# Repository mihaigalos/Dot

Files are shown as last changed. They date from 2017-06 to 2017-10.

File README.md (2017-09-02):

# Dot

The Dot is a carrier board designed in Eagle, aimed at gathering sensor data from a variety of sensors and sending them over radio.
Its small design and supply from a coin cell battery make it ideal for deployment anywhere.

Features :
* AtMega328p MCU
* RFM12b / RFM69CW Radio module (pin-compatible)
* On-board ceramic antenna
* CAT24M010TS EEPROM (128kByte)
* AT25SF081 Flash (1MByte)
* Breakout of I2C, SPI and UART-TXD
* Breakout of ADC Pin with pads for on-board divider resistor
* Antenna tuning pads for antenna calibration
* uFL connector for external antenna support 
* Sensors
  * MPU-9250 Movement sensor (9DoF : accelerometers, gyros and magnetometer)
  * TMP102 Temperature and Humidity
  * SI1145 UV Index
  * ISL29125 RGB color
  * Analog light sensor

# License
The Dot is Open Hardware. Use it at your own whim and risk, please share if you find it useful.

<p align="center"> 
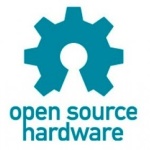
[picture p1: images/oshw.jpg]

</p>

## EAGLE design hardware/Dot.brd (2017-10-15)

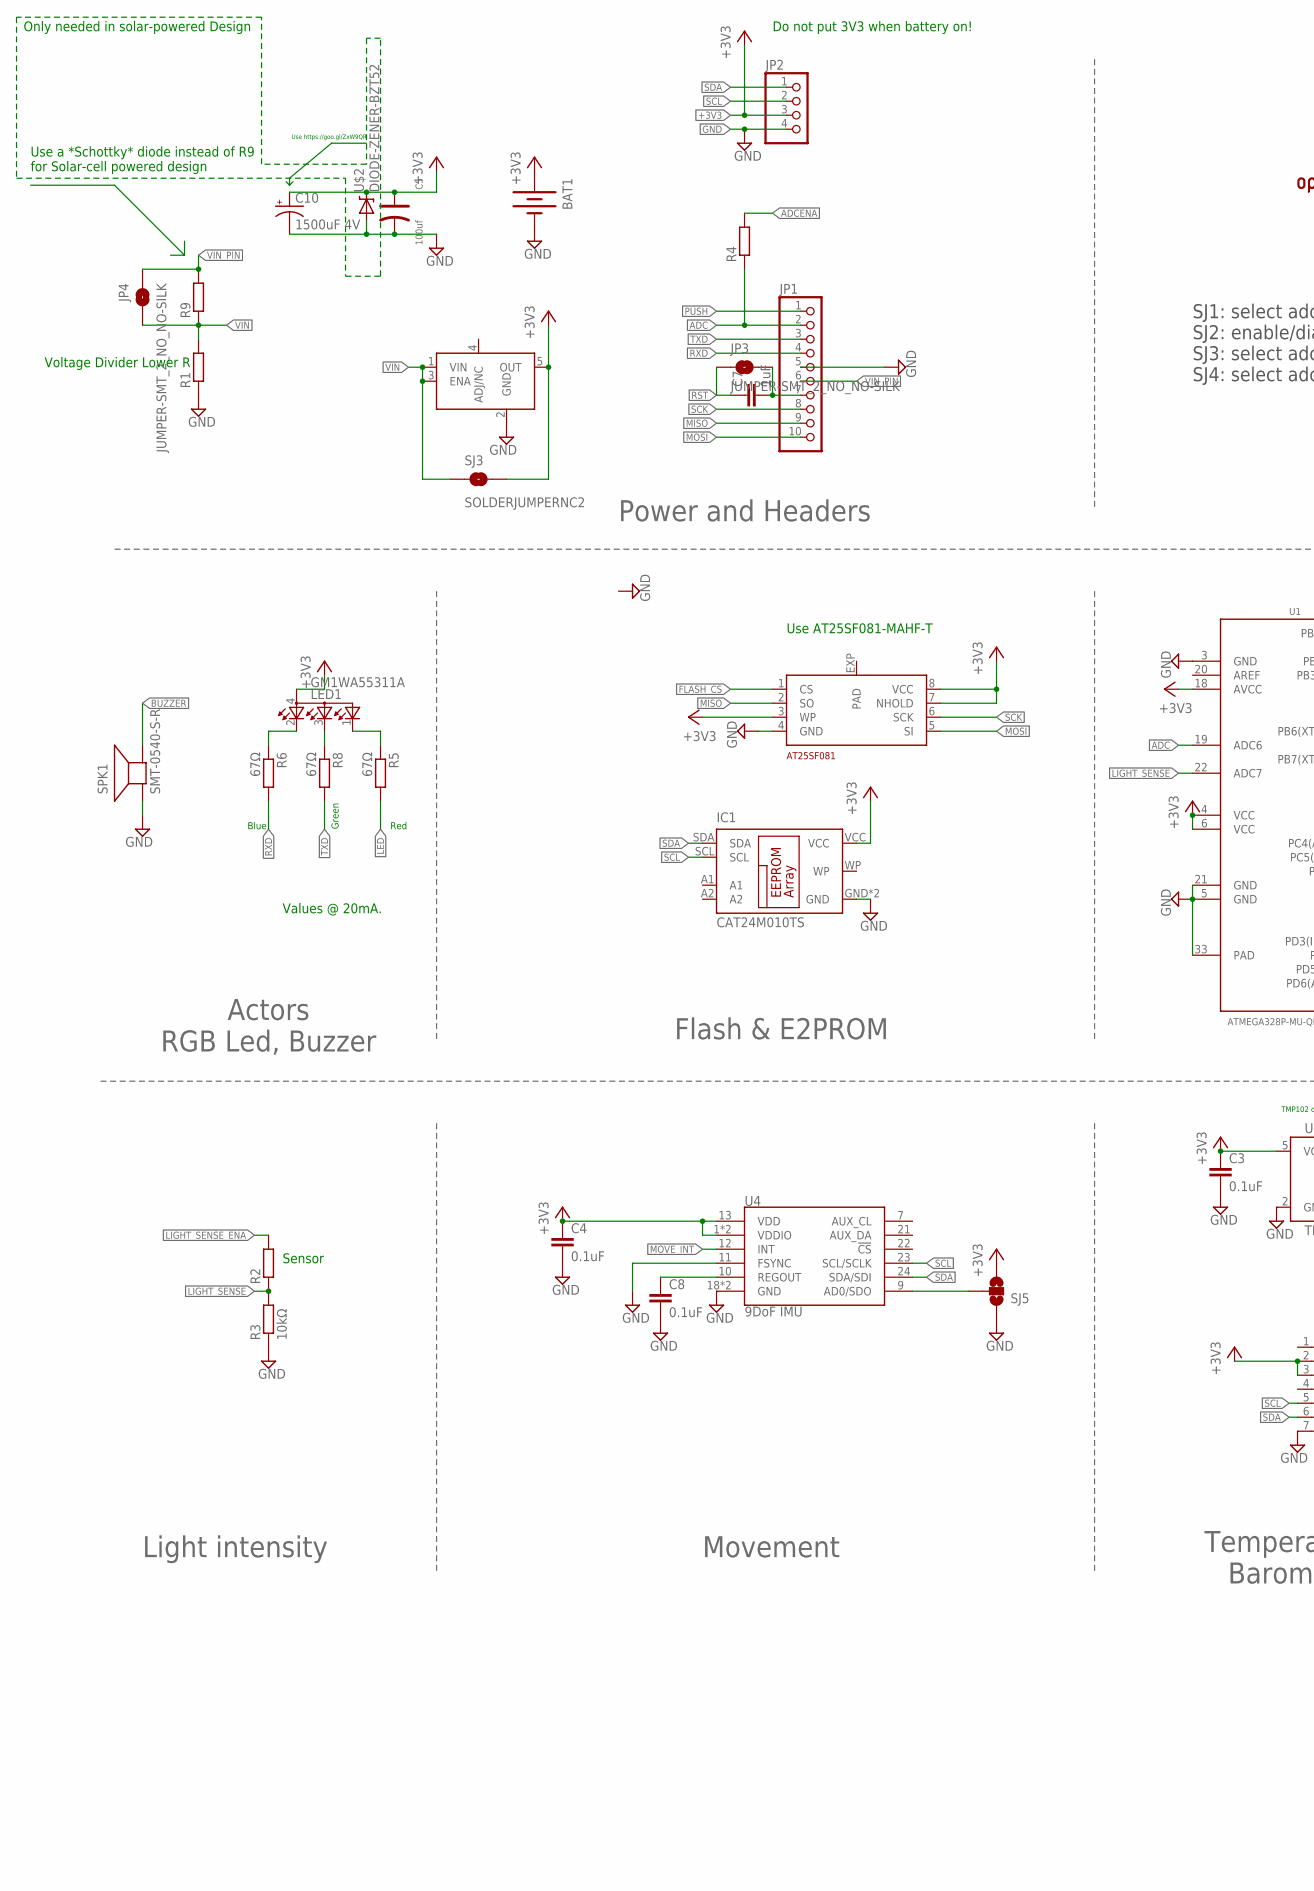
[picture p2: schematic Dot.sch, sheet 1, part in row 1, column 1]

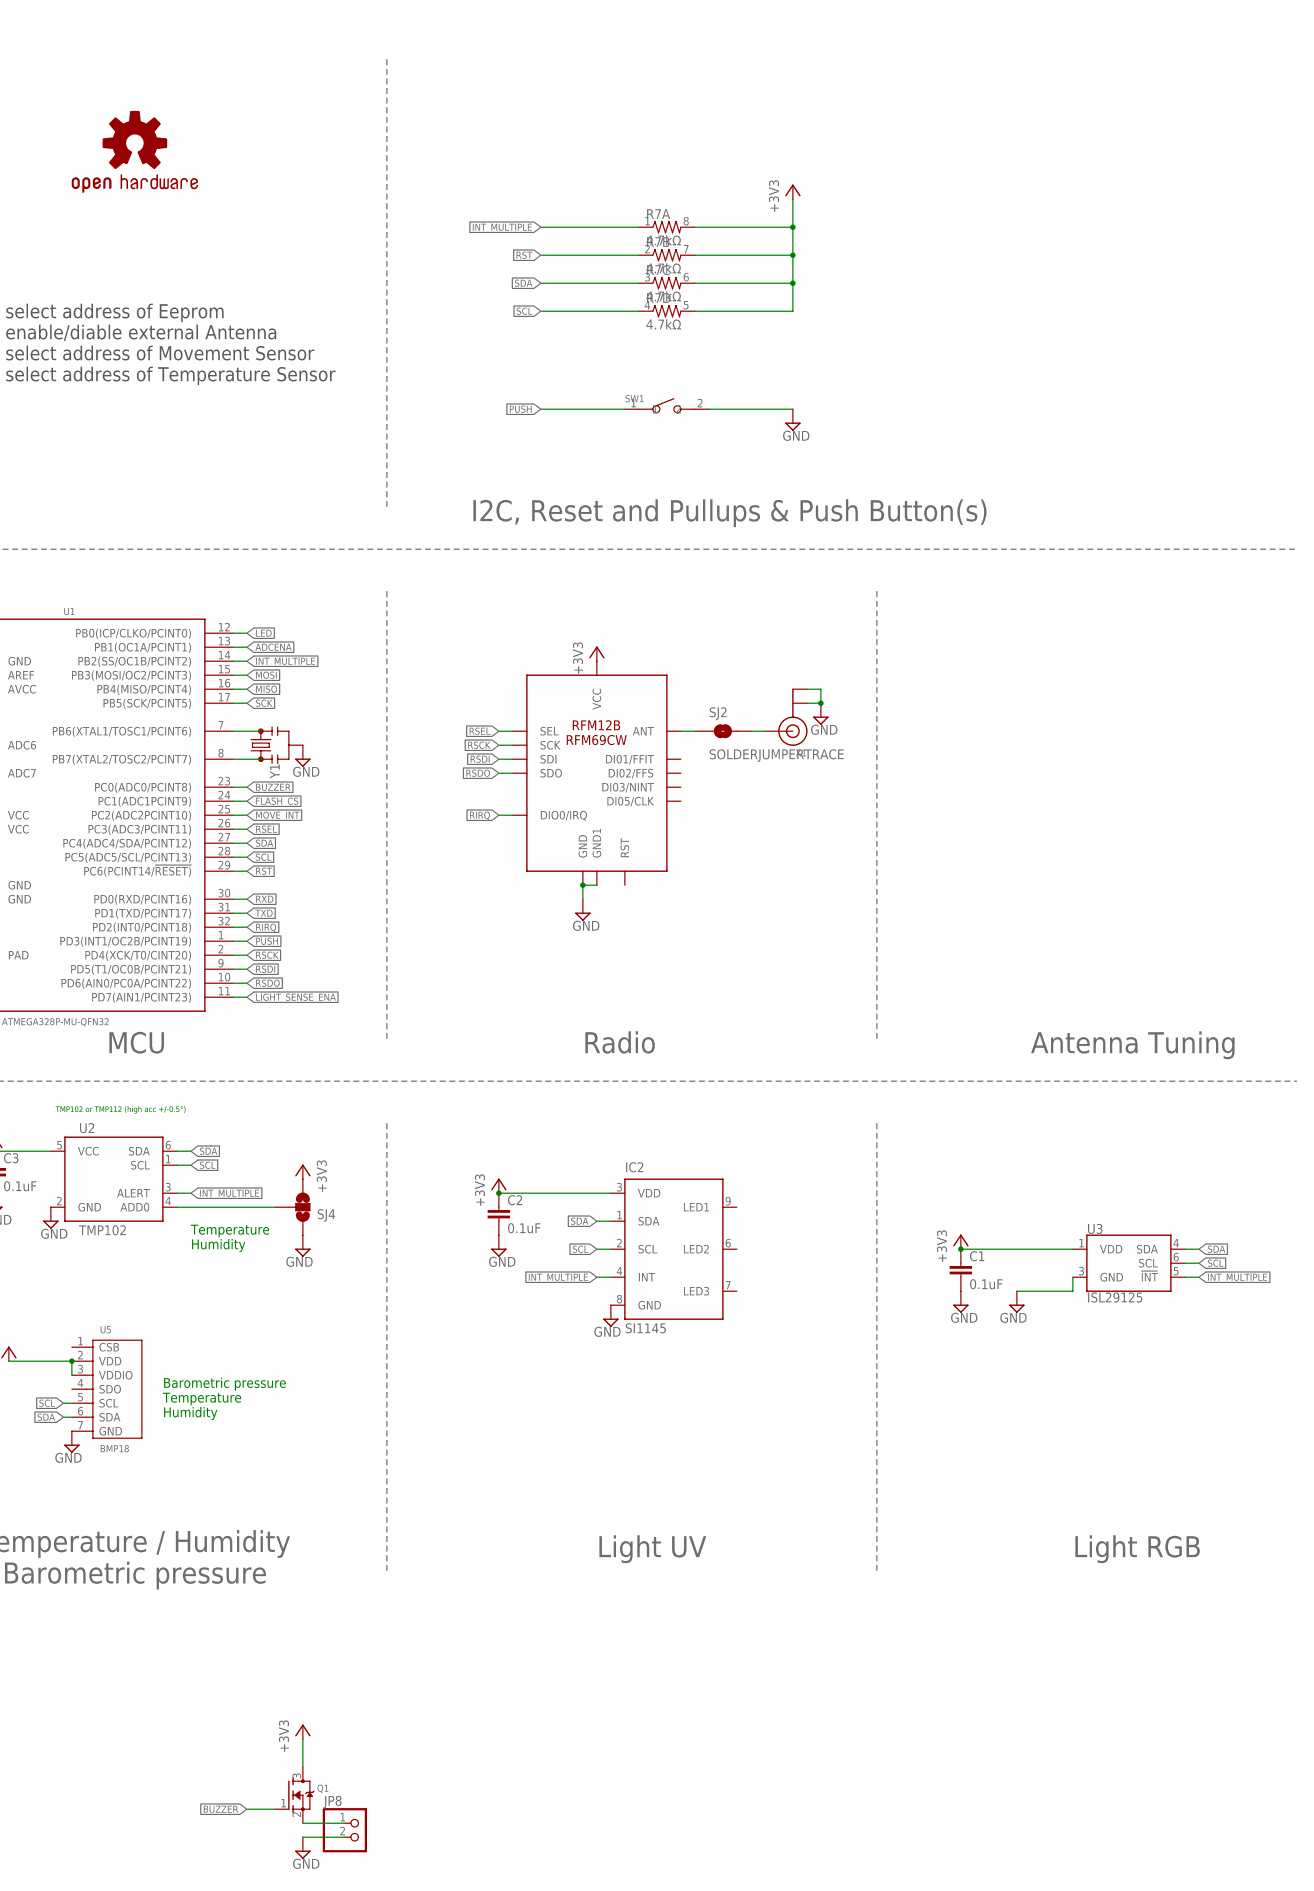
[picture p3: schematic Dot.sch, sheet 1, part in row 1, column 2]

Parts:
BAT1: BATTERY20PTH; BATTCOM_20MM_PTH
C1, C2, C3, C4, C8: 0.1uF; C0603
C5: 100uf; AVX-A
C7: 1uF; C0603
C10: 1500uF 4V; CT7343
IC1: CAT24M010TS; TSSOP8
IC2: SI1145; QFN-10
JP1: PINHD-1X10; 1X10
JP2: PINHD-1X4; 1X04
JP3, JP4: JUMPER-SMT_2_NO_NO-SILK; SMT-JUMPER_2_NO_NO-SILK
JP8: PINHD-1X2; 1X02
LED1: GM1WA55311A
LOGO1: OSHW-LOGOS; OSHW-LOGO-S
Q1: MOSFET-NREFLOW; SOT23
R1, R4, R9: R-EU_R0603; R0603
R2: R-EU_R0805; R0805
R3: 10kΩ; R0603
R5, R6, R8: 67Ω; R0603
R7: 4.7kΩ; 0603-ARV
SJ2: SOLDERJUMPERTRACE; SJ_2S-TRACE
SJ3: SOLDERJUMPERNC2; SJ_2S-NOTRACE
SJ4, SJ5: SOLDERJUMPER_2WAYS; SJ_3
SPK1: SMT-0540-S-R
SW1: SMD-BUTTON(2P-6.0X3.0X2.5MM)-DHT-1163S; SW2-4.0-6.0X3.0X2.5MM
U1: ATMEGA328P-MU-QFN32; QFN32G-0.5-5X5MM
U2: TMP102; SOT563
U3: ISL29125; ODFN-6
U4: 9DoF IMU; QFN24-3X3
U5: BMP18; LGA7-1.5-3.8X3.6MM
U$1: RFM12B/69CW
U$2: DIODE-ZENER-BZT52; SOD-323
U$3: AT25SF081; DFN-2X3
U$4: LDCL015; SOT23-5
X1: ANTENNA_U.FL; U.FL
Y1: RESONATORSMD-3.2X1.3; RESONATOR-SMD-3.2X1.3

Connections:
+3V3: BAT1.1 (+), C1.1, C2.1, C3.1, C4.1, C5.+, C10.+, IC1.VCC, IC2.3 (VDD), JP2.3, LED1.4 (A), Q1.3 (D), R7.5 (2), R7.6 (2), R7.7 (2), R7.8 (2), SJ3.2, SJ4.3, SJ5.3, U1.4 (VCC), U1.6 (VCC), U1.18 (AVCC), U2.5 (VCC), U3.1 (VDD), U4.1 (VDDIO), U4.8 (VDDIO), U4.13 (VDD), U5.2 (VDD), U5.3 (VDDIO), U$1.VDD (VCC), U$2.1 (C), U$3.3 (WP), U$3.7 (NHOLD), U$3.8 (VCC), U$4.5 (OUT)
ADC: JP1.2, R4.1, U1.19 (ADC6)
ADCENA: R4.2, U1.13 (PB1(OC1A/PCINT1))
BUZZER: Q1.1 (G), SPK1.+ (-), U1.23 (PC0(ADC0/PCINT8))
FLASH_CS: U1.24 (PC1(ADC1PCINT9)), U$3.1 (CS)
GND: BAT1.2 (-), C1.2, C2.2, C3.2, C4.2, C5.-, C8.2, C10.-, IC1.GND, IC1.NC (GND), IC2.8 (GND), JP1.5, JP2.4, JP8.2, R1.1, R3.1, SJ4.1, SJ5.1, SPK1.- (+), SW1.2, U1.3 (GND), U1.5 (GND), U1.21 (GND), U1.33 (PAD), U2.2 (GND), U3.3 (GND), U4.11 (FSYNC), U4.18 (GND), U4.20 (GND), U5.7 (GND), U$1.GND, U$1.GND1, U$2.2 (A), U$3.4 (GND), U$4.2 (GND), X1.1 (GND), X1.2 (GND), Y1.2
INT_MULTIPLE: IC2.4 (INT), R7.1, U1.14 (PB2(SS/OC1B/PCINT2)), U2.3 (ALERT), U3.5 (!INT)
LED: R5.2, U1.12 (PB0(ICP/CLKO/PCINT0))
LIGHT_SENSE: R2.1, R3.2, U1.22 (ADC7)
LIGHT_SENSE_ENA: R2.2, U1.11 (PD7(AIN1/PCINT23))
MISO: JP1.9, U1.16 (PB4(MISO/PCINT4)), U$3.2 (SO)
MOSI: JP1.10, U1.15 (PB3(MOSI/OC2/PCINT3)), U$3.5 (SI)
MOVE_INT: U1.25 (PC2(ADC2PCINT10)), U4.12 (INT)
unnamed: LED1.3 (CBLUE), R8.1
unnamed: SJ2.1, U$1.ANT
unnamed: LED1.2 (CRED), R6.1
unnamed: C7.2, JP1.7, JP3.2
unnamed: U1.7 (PB6(XTAL1/TOSC1/PCINT6)), Y1.3
unnamed: SJ2.2, X1.3 (SIGNAL)
unnamed: U1.8 (PB7(XTAL2/TOSC2/PCINT7)), Y1.1
unnamed: SJ4.2, U2.4 (ADD0)
unnamed: C8.1, U4.10 (REGOUT)
unnamed: SJ5.2, U4.9 (AD0/SDO)
unnamed: LED1.1 (CGREEN), R5.1
unnamed: JP8.1, Q1.2 (S)
PUSH: JP1.1, SW1.1, U1.1 (PD3(INT1/OC2B/PCINT19))
RIRQ: U1.32 (PD2(INT0/PCINT18)), U$1.IRQ (DIO0/IRQ)
RSCK: U1.2 (PD4(XCK/T0/CINT20)), U$1.SCK
RSDI: U1.9 (PD5(T1/OC0B/PCINT21)), U$1.SDI
RSDO: U1.10 (PD6(AIN0/PC0A/PCINT22)), U$1.SDO
RSEL: U1.26 (PC3(ADC3/PCINT11)), U$1.SEL
RST: C7.1, JP3.1, R7.2 (1), U1.29 (PC6(PCINT14/!RESET))
RXD: JP1.4, R6.2, U1.30 (PD0(RXD/PCINT16))
SCK: JP1.8, U1.17 (PB5(SCK/PCINT5)), U$3.6 (SCK)
SCL: IC1.SCL, IC2.2 (SCL), JP2.2, R7.4 (1), U1.28 (PC5(ADC5/SCL/PCINT13)), U2.1 (SCL), U3.6 (SCL), U4.23 (SCL/SCLK), U5.5 (SCL)
SDA: IC1.SDA, IC2.1 (SDA), JP2.1, R7.3 (1), U1.27 (PC4(ADC4/SDA/PCINT12)), U2.6 (SDA), U3.4 (SDA), U4.24 (SDA/SDI), U5.6 (SDA)
TXD: JP1.3, R8.2, U1.31 (PD1(TXD/PCINT17))
VIN: JP4.2, R1.2, R9.1, SJ3.1, U$4.1 (VIN), U$4.3 (ENA)
VIN_PIN: JP1.6, JP4.1, R9.2

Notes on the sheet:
Sensor
Do not put 3V3 when battery on!
SJ1: select address of Eeprom SJ2: enable/diable external Antenna SJ3: select address of Movement Sensor SJ4: select address of Temperature Sensor
Movement
Light UV
Light intensity
Flash & E2PROM
MCU
Radio
Light RGB
Actors RGB Led, Buzzer
Antenna Tuning
Power and Headers
I2C, Reset and Pullups & Push Button(s)
Values @ 20mA.
Barometric pressure Temperature Humidity
Temperature / Humidity Barometric pressure
Temperature Humidity
TMP102 or TMP112 (high acc +/-0.5°)
Blue
Green
Red
Voltage Divider Lower R
Use https://goo.gl/ZxW9QR
Use a *Schottky* diode instead of R9 for Solar-cell powered design
Only needed in solar-powered Design
Use AT25SF081-MAHF-T

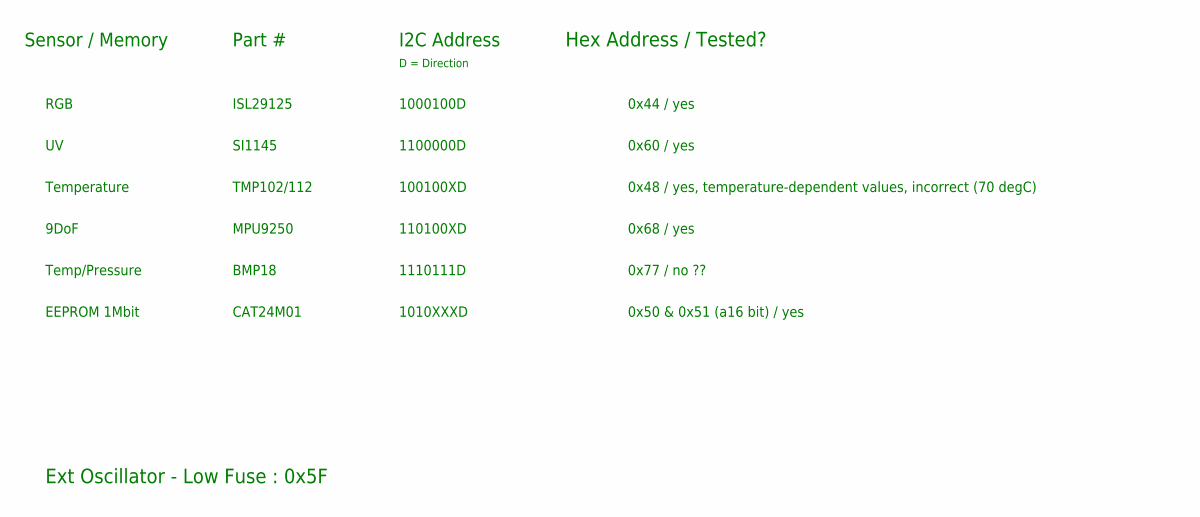
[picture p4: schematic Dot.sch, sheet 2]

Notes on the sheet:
Sensor / Memory
Part #
I2C Address
RGB
ISL29125
1000100D
SI1145
1100000D
Temperature
TMP102/112
100100XD
9DoF
MPU9250
110100XD
Hex Address / Tested?
0x44 / yes
0x60 / yes
Temp/Pressure
BMP18
1110111D
0x77 / no ??
0x48 / yes, temperature-dependent values, incorrect (70 degC)
EEPROM 1Mbit
CAT24M01
1010XXXD
0x50 & 0x51 (a16 bit) / yes
D = Direction
0x68 / yes
Ext Oscillator - Low Fuse : 0x5F

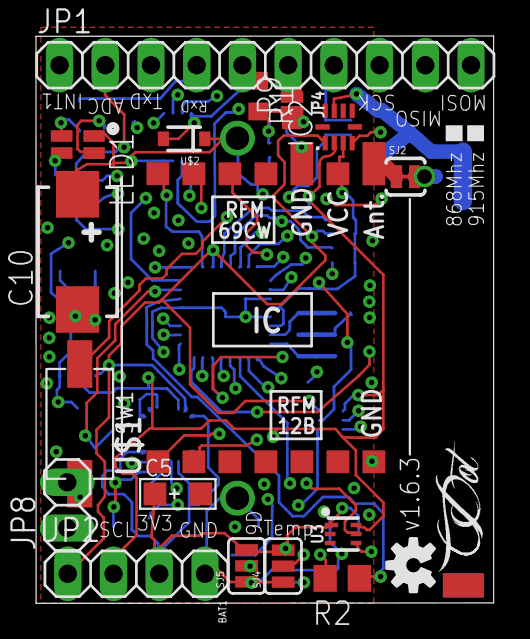
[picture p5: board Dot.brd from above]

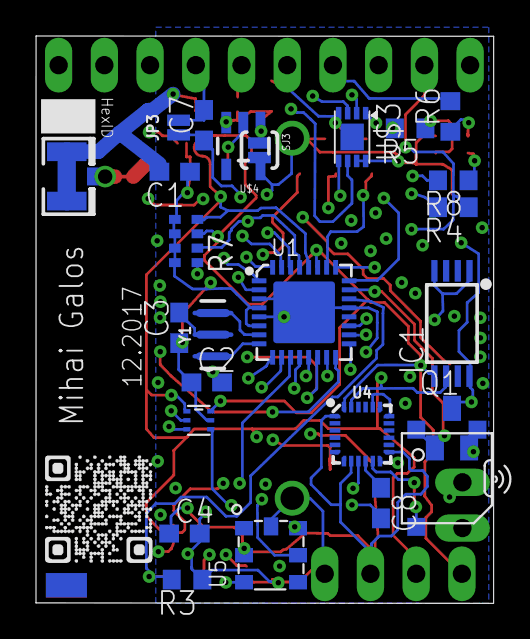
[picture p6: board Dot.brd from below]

Board: 4 copper layers, 25.4 x 31.5 mm, 45 parts (25 on the bottom side), 39 nets.

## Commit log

2017-01-22 adding pdf schematic
2017-01-22 udpating schematic
    [Dot.sch]
2017-06-13 * Corrected RGB Led layout * Added 100uF Cap. Should soften discharges up to 30mA for 1ms. * Cap recharges in 175ms.
    [Dot.brd, Dot.sch]
2017-06-28 Moving lower 100uF Cap to leave room fo the 3V3 and GND labels.
    [Dot.brd]
2017-06-28 Added voltage divider for input voltage measuring.
    [Dot.brd, Dot.sch]
2017-06-28 Adding solderjumper for bypassing Voltage Regulator
    [Dot.brd, Dot.sch]
2017-06-28 Removing schematic.pdf since development still ongoing
2017-06-29 Added cap for Reset via DTR pin / Easy Arduino upload
    [Dot.brd, Dot.sch]
2017-09-02 Add holes for sawing off if necessary
    [Dot.brd]
2017-09-02 Update led : G(TxD) B(RxD) R(LED)
    [Dot.brd, Dot.sch]
2017-09-02 Readd QR, improve labels
    [Dot.brd]
2017-09-02 Move QR to avoid vias
    [Dot.brd]
2017-09-02 Reorder drills for cut
    [Dot.brd]
2017-09-02 Switch to Billy Argel font for Dot and Name words
    [Dot.brd]
2017-09-02 Add pullup to UV, RGB and Temp. Their IRQ share same line
    [Dot.brd, Dot.sch]
2017-09-02 ? Checkpoint
    [Dot.brd]
2017-09-02 Add chrystal oscillator, moved C2 and C3
    [Dot.brd, Dot.sch]
2017-09-02 Move chrystal and C2 down to balance osc l-r length
    [Dot.brd]
2017-09-02 Update to v1.6
    [Dot.brd]
2017-09-02 Adjust HexId, add 868/915 Mhz silk
    [Dot.brd]
2017-09-02 Add C10 1000uF with enough room, move HexID to other side
    [Dot.brd, Dot.sch]
2017-09-02 Remove C9 100uF add Zenner 3.6V
    [Dot.brd, Dot.sch]
2017-09-02 Update description : Use a Schottky instead of R9 for solar cell
    [Dot.brd, Dot.sch]
2017-09-02 Reposition name graphic
    [Dot.brd]
2017-09-02 Add solder joint for antenna on bottom
    [Dot.brd]
2017-09-02 Add jumper for C7 Reset
    [Dot.brd, Dot.sch]
2017-09-02 Refactor name logo to simple text
    [Dot.brd]
2017-09-02 Shift via to make space for text silk
    [Dot.brd]
2017-09-02 Added AT25SF081, fixed labels
    [Dot.brd, Dot.sch]
2017-09-02 Rearranging files
    [Dot.brd, Dot.sch]
2017-09-02 Removing superfluous extra MOSI.
    [Dot.brd]
2017-09-04 Adding pad for soldering end of antenna top/bottom
    [Dot.brd]
2017-09-14 Added MOSFET and pins for external on/off
    [Dot.brd, Dot.sch]
2017-10-15 Moved Miso via away from the 4.7kOhm array, moved graphics further apart
    [Dot.brd, Dot.sch]

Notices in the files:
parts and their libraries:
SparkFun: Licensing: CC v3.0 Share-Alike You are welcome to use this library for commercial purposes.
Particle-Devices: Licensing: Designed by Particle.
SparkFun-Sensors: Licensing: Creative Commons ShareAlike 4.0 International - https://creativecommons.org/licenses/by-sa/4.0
